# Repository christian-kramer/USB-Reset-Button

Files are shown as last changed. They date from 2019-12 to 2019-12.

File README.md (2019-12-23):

# USB-Reset-Button
A button to reset a webcam when its microphone goes haywire

___

My friend in Canada, whom I video call a lot, has a recurring issue with her webcam: her laughter is fairly high-pitched and sharp, which causes the microphone in her webcam to start resonating at a *very* annoying frequency... and it won't stop unless she unplugs it, and plugs it back in again!

Of course, she doesn't know when this issue occurs unless I tell her about it, at which point she has to go digging at the back of her PC to find the right plug... which can take a couple tries! Understandably, she gets pretty aggravated at the webcam every time this happens, now.

I decided that, since this issue happens somewhat frequently, I'm going to do something about it. My vision: a physical button she can press that momentarily interrupts the power going to the webcam, causing it to reboot. The webcam should plug into it, and then it should plug into the PC... sort of "man-in-the-middle"-ing the webcam's power supply.

Rough Sketch

Alright, this looks good! Time to go to Ax-Man Surplus to find supplies. I decided to hit up their Fridley location for the first time, since I was in the neighborhood. From what I can tell, Fridley's got the best selection of switches and buttons. I found this fantastic pinball flipper button; very durable, perfect for my friend to smack the next time her webcam acts up. This was a good "interface", but it's purely mechanical. I still need a momentary switch to do the electrical work. Preferably, one that is "normally closed" so the webcam gets power when the button *isn't* pressed. Eventually, browsing the aisles, I stumbled upon the *perfect* momentary switch for the job. Plenty of travel, but the "click" happens almost instantly with the slightest bit of pressure applied. Only one problem - the switch has two terminals, and it's "normally open", meaning it'll only deliver power when pressed. No worries! This should be an easy fix, we just need a transistor to invert the switch. Luckily, Ax-Man has plenty of those!

I opted for a P-Channel Mosfet, because I wanted to switch the +5 volt supply rail of the USB bus. Implementing this transistor would be very easy if our switch had 3 pins: "closed", "open", and "common"... We could just toggle the gate between +5v and GND. But our switch only has 2 pins, which means we need a pull down resistor to keep the gate held at GND until the switch, connecting the gate and +5v, is pressed. Here's my circuit:

Circuit

The USB data pins and GND are just passed through, but the switching happens on the high-side (as described).

Looks good! And it's simple... easy to breadboard. When I built the circuit, and plugged a USB flash drive in to test, it worked beautifully! When I connected the wires to simulate the switch being pressed, the flash drive disappeared... then re-appeared when I simulated the switch being released! Next, I tried plugging in the webcam... but that failed! I couldn't get an image, or the device itself to be recognized in Windows. It just didn't work. Why would the flash drive work, but the webcam not?!

But then, it occurred to me... What if the webcam requires a high enough data speed to necessitate a "twisted pair" data line?

Twisted Pair is what you see in cables such as telephone or ethernet (or USB). Data is transmitted via alternating current to facilitate long-distance communication, and each "pair" of data lines is twisted together to reduce noise. By taking the two jumpers on my breadboard and twisting them together, the webcam suddenly started working! A crystal-clear picture, interrupted by the connecting of the "button" jumper.

Time to design an enclosure!

Recently, I bought an Ender 3 Pro 3D printer, so I whipped up a design in Cinema 4D and printed out an enclosure.

Render

After a couple of revisions, everything fit perfectly!

Fit

Here's an up-close look at the perfboard connections. I decided against making a custom PCB because I've never used perfboard in a project before, and because it's a one-off with parts I likely won't be able to find again, I figured it was worth practicing my makeshift prototyping skills. At the very least, it was certainly cheaper and faster than waiting for a shipment from Shenzhen to come in!

Close-up

And here's an up-close look at the  USB connectors. Just like in the 3D model, they fit perfectly! I specifically designed it to fit my friend's computer desk setup. As shown in the first image at the very top, her webcam is to the left of the computer, so I put the plug for the webcam on the left side of the button, and the plug for the computer on the right side. This way, no wires have to cross.

USB

Exterior

Exterior 2

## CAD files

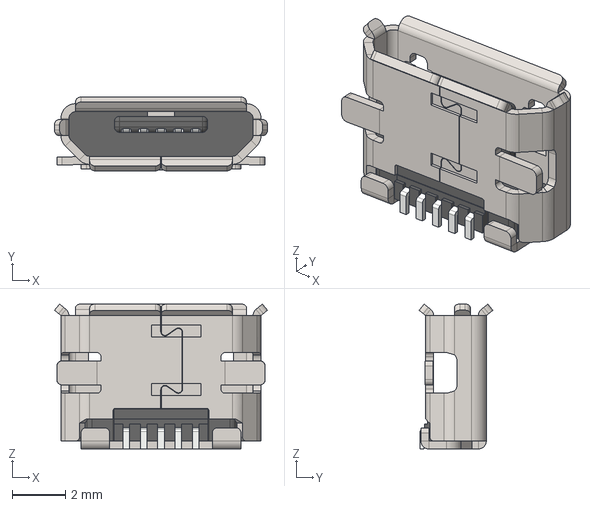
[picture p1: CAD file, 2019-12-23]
Mechanical/CAD Parts/molex_0473460001.STEP
7.98 x 2.76 x 5.43 mm

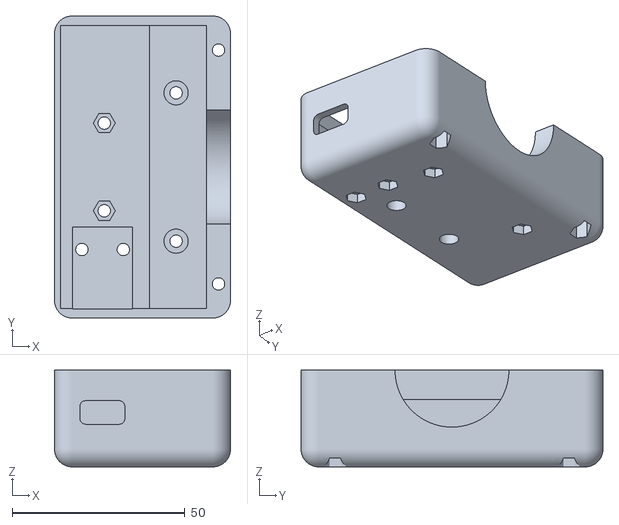
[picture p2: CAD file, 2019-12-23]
Mechanical/Switch Shell With Standoffs and USB Test Revised.stl
51.0 x 87.5 x 28.0

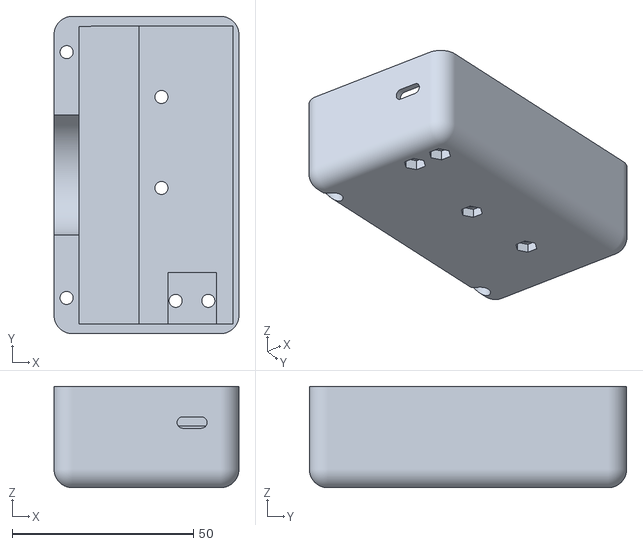
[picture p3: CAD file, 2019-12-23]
Mechanical/Button Shell With Micro USB.stl
51.0 x 87.5 x 28.0

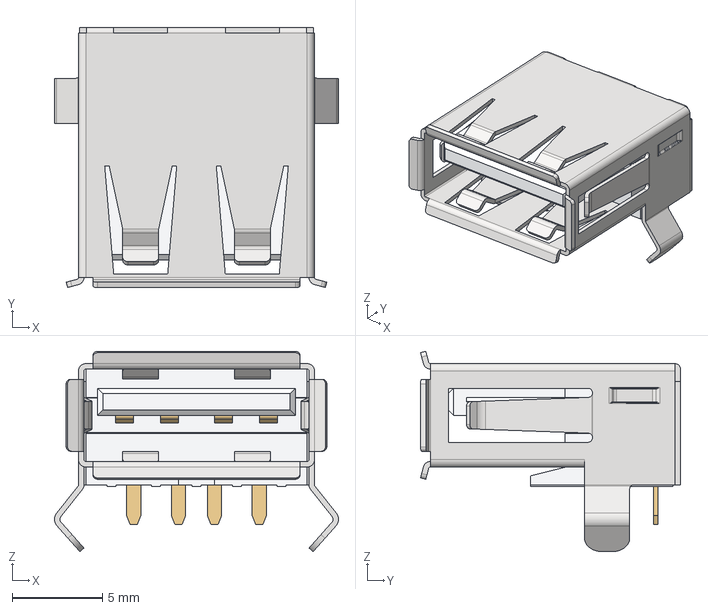
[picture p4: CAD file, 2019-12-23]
Mechanical/CAD Parts/femaleThruHoleUSB.stp
15.8 x 14.4 x 11.1 mm

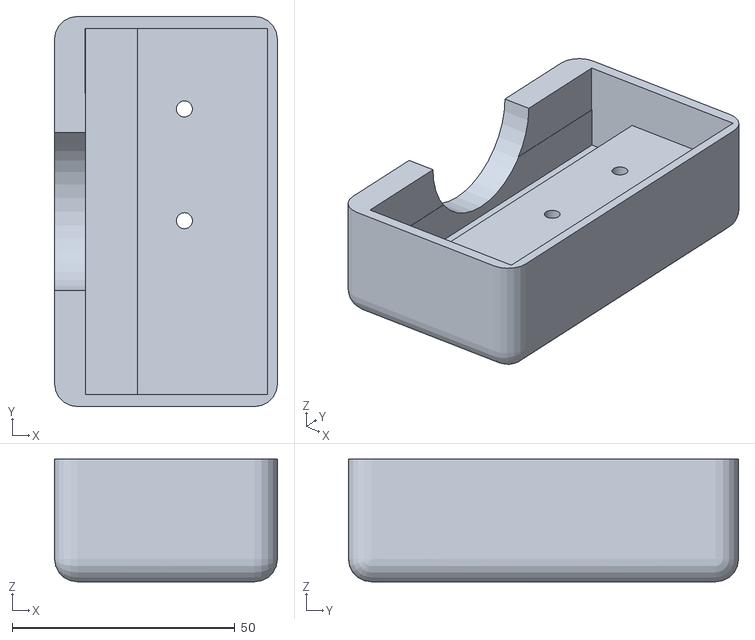
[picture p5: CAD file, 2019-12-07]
Mechanical/Button Shell.stl
50.0 x 87.5 x 27.5

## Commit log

2019-12-07 first test printing
    [Button Shell.stl, USB Reset Button.kicad_pcb, USB Reset Button.sch]
2019-12-23 Updated Mechanical Parts
    [Button Shell With Micro USB.stl, Switch Shell With Standoffs and USB Test Revised.stl, femaleThruHoleUSB.stp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]
2019-12-23 Updated Electrical Schematic
    [USB Reset Button.sch]
